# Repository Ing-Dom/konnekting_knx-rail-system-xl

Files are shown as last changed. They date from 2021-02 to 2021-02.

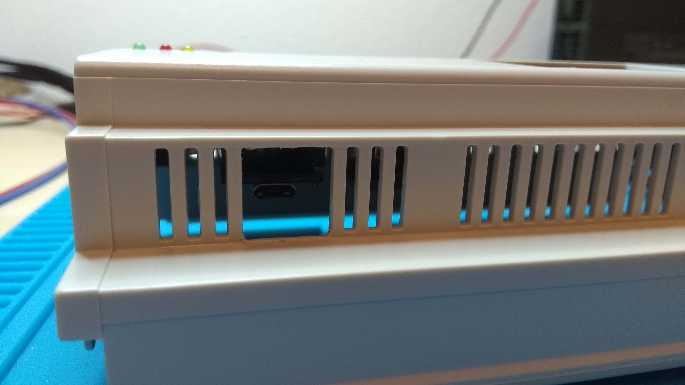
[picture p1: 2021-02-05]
hardware/KRS-XL_CB6-9-12/Pictures/IMG_20200106_220313494.jpg

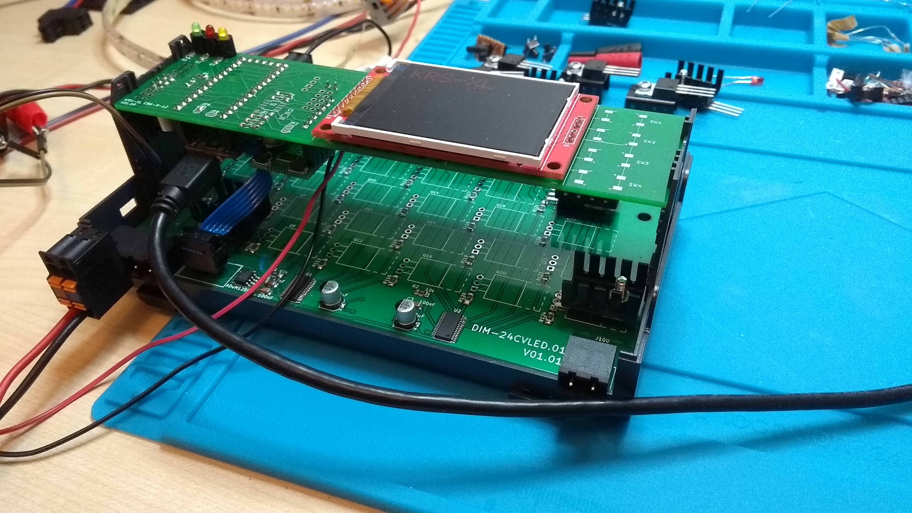
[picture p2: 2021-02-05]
hardware/KRS-XL_CB6-9-12/Pictures/IMG_20200125_214552915.jpg

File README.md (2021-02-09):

# KNX Rail System XL

The KNX Rail System XL (KRS-XL) is a bunch of modular hard- and software for building DIY KNX devices in big DIN Rail Casings (6, 9 and 12 TE). It is designed for applications with a high number of channels. 

For more information please visit the [wiki](https://gitlab.com/knx-makerstuff/knx-rail-system-xl/-/wikis/home)

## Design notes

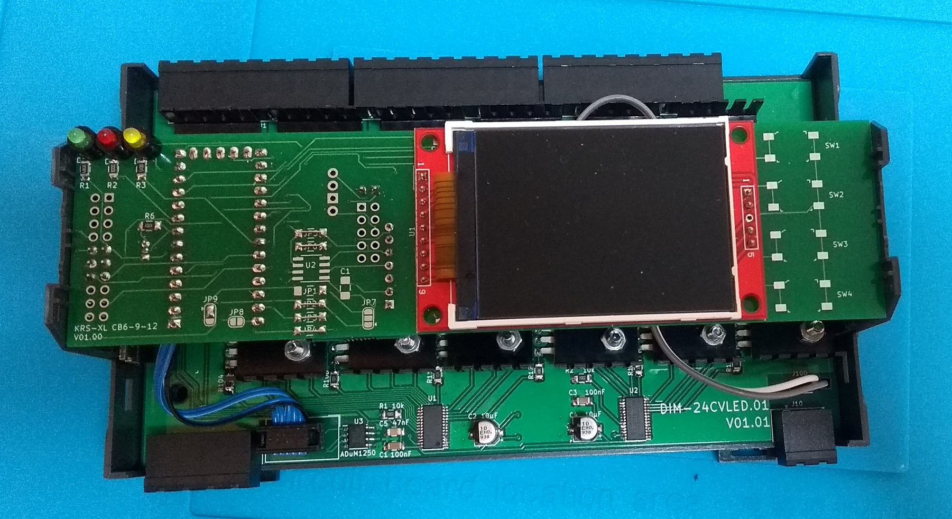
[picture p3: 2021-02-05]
hardware/KRS-XL_CB6-9-12/Pictures/IMG_20200126_205323381 - Kopie.jpg

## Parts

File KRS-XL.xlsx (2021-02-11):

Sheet: BOM
 |  |  |  | Supplier |  |  | Alt 1 |  |  |  | DIM-24CxLED (TFT)
Num | Ref | Desc | Element desc. | Supplier | ORDER-NR | Cost | Supplier | ORDER-NR | Cost
1 |  | PCB |  | KNX Makerstuff | 0100 | 4.00 € |  |  |  | 4.00 € | X
1 | J2 | Wannenstecker | Wannenstecker, 20-polig, gerade | Reichelt | WSL 20G | 0.15 € |  |  |  | 0.15 € | WSL 6G
1 | D1 | Power LED | LED, 3 mm, bedrahtet, grün, 3,2 mcd, 60° | Reichelt | LED 3MM 2MA GN | 0.12 € |  |  |  | 0.12 € | X
1 | D2 | Prog LED | LED, 3 mm, bedrahtet, rot, 3,2 mcd, 60° | Reichelt | LED 3MM 2MA RT | 0.12 € |  |  |  | 0.12 € | X
1 | D3 | Error LED | LED, 3 mm, bedrahtet, gelb, 3,2 mcd, 60° | Reichelt | LED 3MM 2MA GE | 0.12 € |  |  |  | 0.12 € | X
3 | D1-3 | LED Abstandshalter | Abstandhalter für 3 mm LEDs, Länge 5 mm | Reichelt | MEN 2818.3045 | 0.20 € |  |  |  | 0.60 € | X
1 | R1 | Vorwiderstand Power LED | SMD1206 680R | Reichelt | RND 1206 1 680 | 0.02 € |  |  |  | 0.02 € | X
1 | R2 | Vorwiderstand Prog LED | SMD1206 850R | Reichelt | RND 1206 1 820 | 0.02 € |  |  |  | 0.02 € | X
1 | R3 | Vorwiderstand Error LED | Element desc. | Reichelt | RND 1206 1 510 | 0.02 € |  |  |  | 0.02 € | X
1 | U3 | Temp Sensor | DS 18B20 | Reichelt | DS 18B20 | 1.75 € |  |  |  | 1.75 € | X
1 | R6 | DS18B20 Onewire Pullup | SMD1206 4k7 | Reichelt | RND 1206 1 4,7K | 0.02 € |  |  |  | 0.02 € | X
1 | C10 | Decoupling C µC 100N | SMD 1206 100N | Reichelt | KEM X7R1206B100N | 0.04 € |  |  |  | 0.04 € | X
1 | C11 | Decoupling C µC 10µF | 10µF | Reichelt | HD-V 10U 25 | 0.25 € |  |  |  | 0.25 € | X
2 | R4-5 | I2C Pullup | SMD1206 1k | Reichelt | RND 1206 1 1,0K | 0.02 € |  |  |  | 0.04 € | X
1 | GN1 | MicroBCU2 | MicroBCU2 | KNX Makerstuff | 0001 | 10.00 € |  |  |  | 10.00 € | X
1 | GN1 | 1x07 Buchsenleiste low profile µBCU | Buchsenleiste 1x7 | Reichelt | BL 1X10G8 2,54 | 0.21 € |  |  |  | 0.21 € | MPE 094-1-007
1 | GN1 | 1x07 Stiftleiste | Stiftleiste 1x7 | Reichelt | MPE 087-1-007 | 0.16 € |  |  |  | 0.16 € | X
1 | J1 | Header for KNX+/GND | Stiftleiste 1x2 | Reichelt | RND 205-00623 | 0.03 € |  |  |  | 0.03 € | X
1 | GN2 | Controllerboard | Adafruit ItsyBitsyM0 Express SAMD21 µC Board | DigiKey | ItsyBitsy M0 | 12.70 € | Antratek |  | 11.84 € | 12.70 € | X
2 | GN2 | 1x14 female header low profile für Controllerboard | 20pol. Buchsenleiste, gerade, RM 2,54 5mm | Reichelt | BL 1X20G 2,54 | 0.72 € |  |  |  | 1.44 € | MPE 094-1-016
1 | GN2 | 1x05 female header low profile für Controllerboard | use rest | use rest | use rest | 0.00 € |  |  |  | 0.00 € | MPE 094-1-005
1 | U1 | Display | TFT 240x320 ILI9341 2.2" | ebay | ILI9341 2.2 SPI TFT | 5.50 € |  |  |  | 5.50 € | X
4 | SW1-4 | Taster Display | SMD-Kurzhubtaster, vert. Montage, Höhe 9,5mm | Reichelt | TASTER 9319 | 0.27 € |  |  |  | 1.08 € | X
2 | C1-2 | C for magnetic coupler | SMD1206 10-100N | Reichelt | RND 1501206B4733 | 0.02 € |  |  |  | 0.04 €
1 | GN3 | Siemens BCU | Siemens Busankoppler KNX 5WG1 117-2AB12 | Voltus | UP117/12 | 25.00 € |  |  |  | 25.00 €
8 | D10-D17 | 3mm LED for LED Matrix | LED, 3 mm, bedrahtet, grün, 18 mcd, 60° | Reichelt | LED 3MM GN | 0.07 € |  |  |  | 0.56 €
8 | D10-D17 | LED Abstandshalter | Abstandhalter für 3 mm LEDs, Länge 5 mm | Reichelt | MEN 2818.3045 | 0.20 € |  |  |  | 1.60 €
3 | R10-12 | Vorwiderstand LED Matrix | SMD1206 ??? R | Reichelt | RND 1206 1 ??? | 0.02 € |  |  |  | 0.06 €
8 | SW10-17 | Taster für Tastermatrix | SMD-Kurzhubtaster, vert. Montage, Höhe 9,5mm | Reichelt | TASTER 9319 | 0.27 € |  |  |  | 2.16 €
1 | U2 | magnetic coupler KNX BCU | ADuM1201AR | Reichelt | ADUM 1201 AR | 1.70 € |  |  |  | 1.70 €
1 | U4 | 20V->3V3 DC DC StepDown | Recom R-783.3-0.5 | Conrad | 154481 - U0 | 7.03 € |  |  |  | 7.03 €
2 | GN3 | Lötstifte KNX Klemme Siemens BCU | WAGO Lötstifte für Buchsenklemmen 243-131 | Reichelt | WAGO 243-131 | 0.06 € |  |  |  | 0.12 €
1 | GN3 | 2x05 Stiftleiste Siemens BCU
 |  |  |  |  |  |  |  |  |  | 76.66 €
 | R6 | 4k7
 | SW2 | SW_Push_Dual
 | SW3 | SW_Push_Dual
 | SW4 | SW_Push_Dual
 | U1 | CR2013-MI2120
 | U2 | ADuM1201AR
 | U3 | DS18B20
 | U4 | R-783.3-0.5

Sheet: KRS-XL CB6-9-12 Bestückvariante
Variante | µBCU | Siemens BCU | Adum1201 | DC/DC | JP1 | JP2 | JP3 | JP5 | JP6 | JP7 | JP8 | JP9
µBCU mit VCC2 | 3V3+VCC2 | - | - | - | closed | closed | closed | closed | closed | open | open | je nach App
µBCU | 3V3 | - | - | - | open | closed | closed | closed | closed | open | open | 1+2
µBCU isoliert | 3V3 | - | bestückt | - | open | open | open | open | open | 1+2 | open
Siemens BCU | - | bestückt | bestückt | - | closed | open | closed | open | open | 2+3 | closed | je nach App
Siemens BCU isoliert | - | bestückt | bestückt | - | open | open | open | open | open | 2+3 | open
Siemens BCU mit DC/DC | - | bestückt | bestückt | bestückt | closed | open | closed | open | open | 2+3 | open | je nach App
isolated BCU and 5V power from app |  |  |  |  |  |  |  |  |  |  | closed | 2+3
isolated bcu and 3v3 power from app |  |  |  |  |  |  |  |  |  |  | open | 1+2

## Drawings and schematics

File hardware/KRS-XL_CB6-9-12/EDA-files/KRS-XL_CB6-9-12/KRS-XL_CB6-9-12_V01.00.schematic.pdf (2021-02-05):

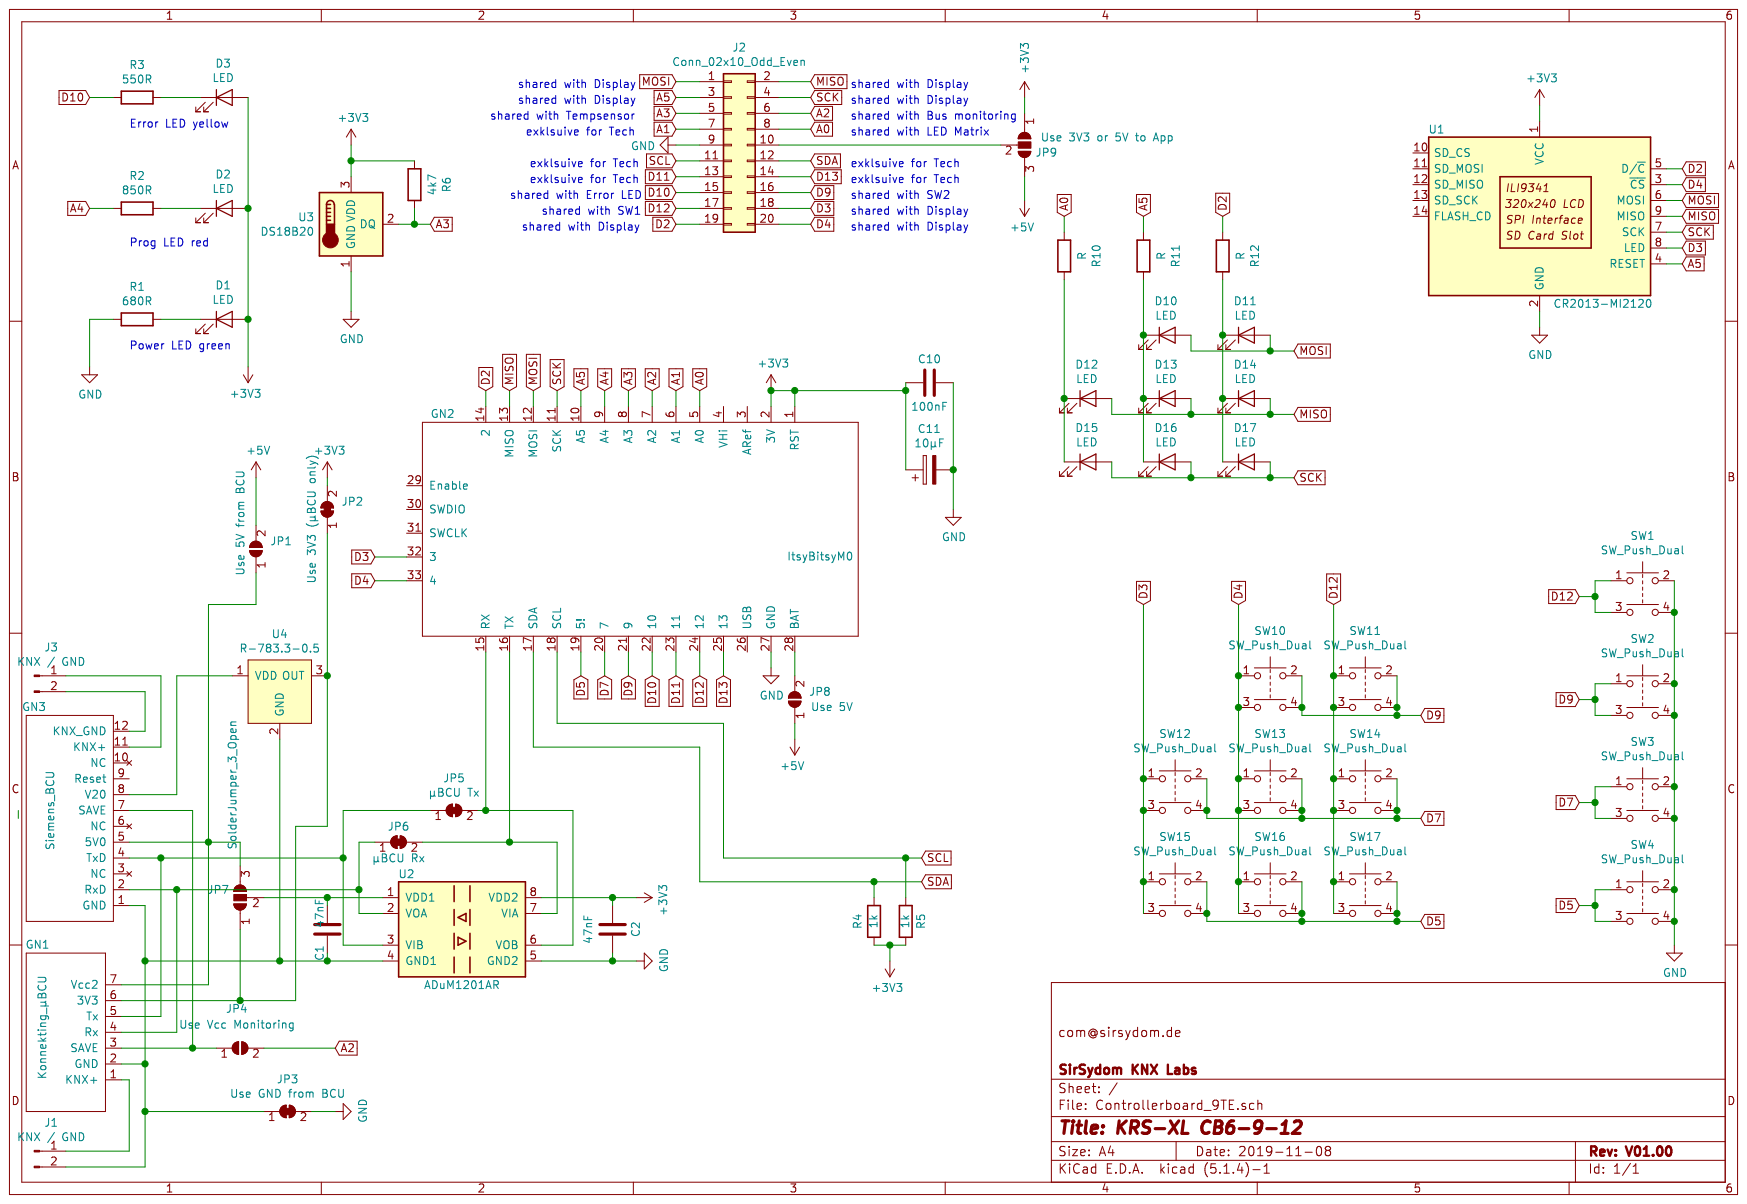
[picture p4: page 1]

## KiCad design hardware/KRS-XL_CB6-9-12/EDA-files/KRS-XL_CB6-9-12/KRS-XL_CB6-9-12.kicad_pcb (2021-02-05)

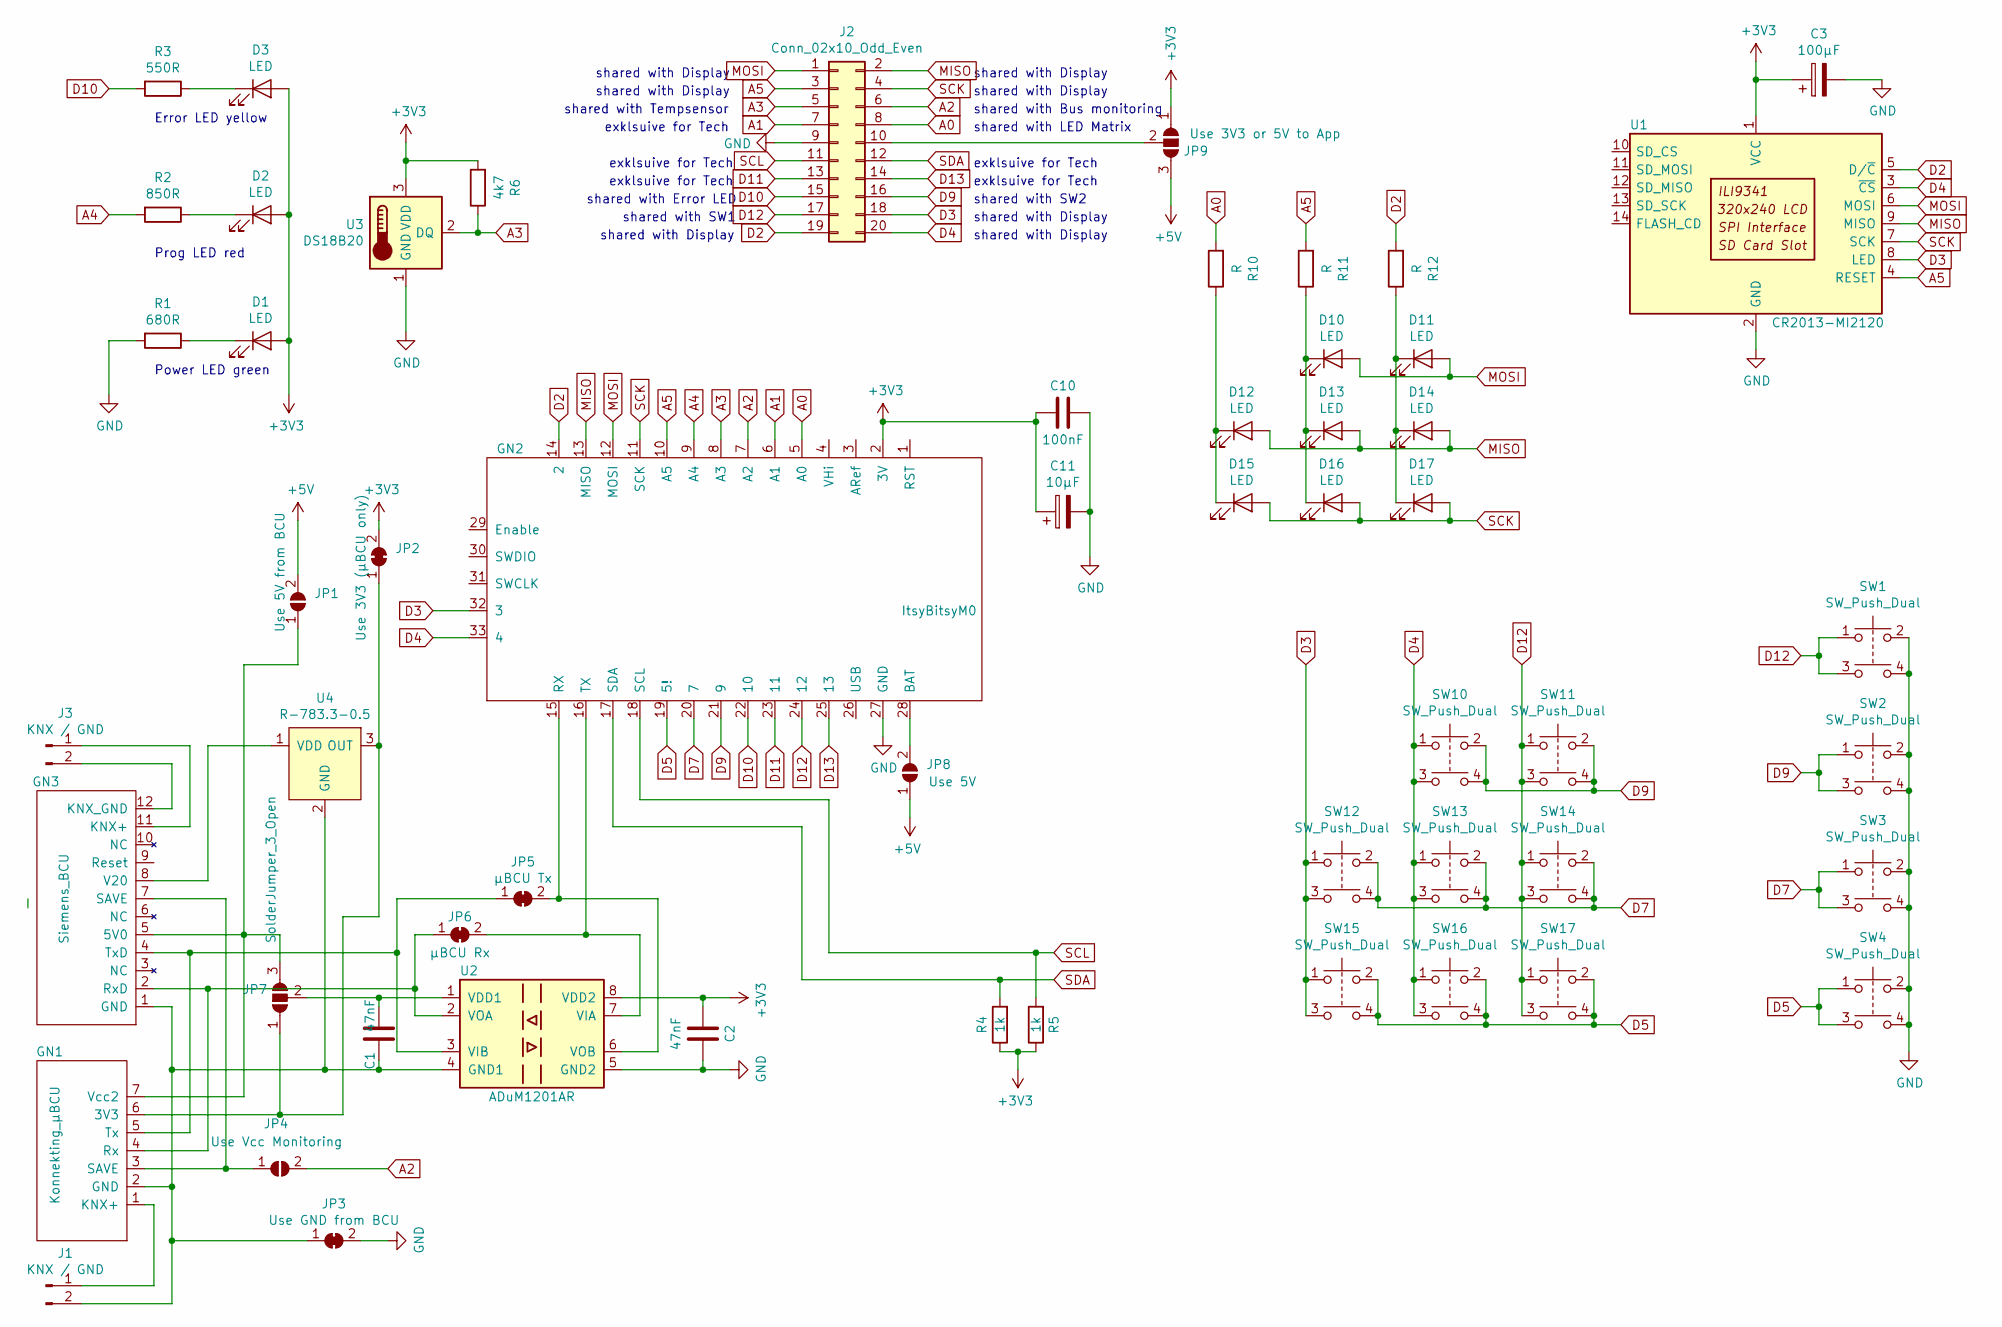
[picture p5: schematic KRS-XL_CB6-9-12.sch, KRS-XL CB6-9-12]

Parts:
C1, C2: 47nF; C_1206_3216Metric_Pad1.42x1.75mm_HandSolder
C3: 100µF; CP_Elec_5x5.3
C10: 100nF; C_1206_3216Metric_Pad1.42x1.75mm_HandSolder
C11: 10µF; CP_Elec_5x5.3
D1, D2, D3, D10, D11, D12, D13, D14, D15, D16, D17: LED; LED_D3.0mm_Clear
GN1: Konnekting_µBCU; Konnekting_BCU
GN2: ItsyBitsyM0
GN3: Siemens_BCU; Siemens_UP117_12_flat
J1, J3: KNX / GND; PinHeader_1x02_P2.54mm_Vertical
J2: Conn_02x10_Odd_Even; IDC-Header_2x10_P2.54mm_Vertical
JP1: Use 5V from BCU; 3mm_solderjumper
JP2: Use 3V3 (µBCU only); 3mm_solderjumper
JP3: Use GND from BCU; 3mm_solderjumper
JP4: Use Vcc Monitoring; 3mm_solderjumper
JP5: µBCU Tx; 3mm_solderjumper
JP6: µBCU Rx; 3mm_solderjumper
JP7: SolderJumper_3_Open; SolderJumper-3_P1.3mm_Open_RoundedPad1.0x1.5mm
JP8: Use 5V; SolderJumper-2_P1.3mm_Open_RoundedPad1.0x1.5mm
JP9: Use 3V3 or 5V to App; SolderJumper-3_P1.3mm_Open_RoundedPad1.0x1.5mm
R1: 680R; R_1206_3216Metric_Pad1.42x1.75mm_HandSolder
R2: 850R; R_1206_3216Metric_Pad1.42x1.75mm_HandSolder
R3: 550R; R_1206_3216Metric_Pad1.42x1.75mm_HandSolder
R4, R5: 1k; R_1206_3216Metric_Pad1.42x1.75mm_HandSolder
R6: 4k7; R_1206_3216Metric_Pad1.42x1.75mm_HandSolder
R10, R11, R12: R; R_1206_3216Metric_Pad1.42x1.75mm_HandSolder
SW1, SW2, SW3, SW4, SW10, SW11, SW12, SW13, SW14, SW15, SW16, SW17: SW_Push_Dual; Switch_Tactile_SMD_6x6mm
U1: CR2013-MI2120; CR2013-MI2120_wo_holes
U2: ADuM1201AR; SOIC-8_3.9x4.9mm_P1.27mm
U3: DS18B20; TO-92_Inline
U4: R-783.3-0.5; SIP-3_P2.54mm_OR_4; MPN R-78E5.0-0.5; Digi-Key_PN 945-1648-5-ND

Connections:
+3V3: C2.2, C3.1, C10.2, C11.1, D1.2 (A), D2.2 (A), D3.2 (A), GN2.2 (3V), JP2.2 (B), JP9.1 (A), R4.1, R5.1, R6.2, U1.1 (VCC), U2.8 (VDD2), U3.3 (VDD)
+5V: JP1.2 (B), JP8.1 (A), JP9.3 (B)
A0: GN2.5 (A0), J2.8, R10.2
A1: GN2.6 (A1), J2.7
A2: GN2.7 (A2), J2.6, JP4.2 (B)
A3: GN2.8 (A3), J2.5, R6.1, U3.2 (DQ)
A4: GN2.9 (A4), R2.2
A5: GN2.10 (A5), J2.3, R11.2, U1.4 (RESET)
D2: GN2.14 (2), J2.19, R12.2, U1.5 (D/~C)
D3: GN2.32 (3), J2.18, SW12.1, SW12.3, SW15.1, SW15.3, U1.8 (LED)
D4: GN2.33 (4), J2.20, SW10.1, SW10.3, SW13.1, SW13.3, SW16.1, SW16.3, U1.3 (~CS)
D5: GN2.19 (5!), SW4.1, SW4.3, SW15.2, SW15.4, SW16.2, SW16.4, SW17.2, SW17.4
D7: GN2.20 (7), SW3.1, SW3.3, SW12.2, SW12.4, SW13.2, SW13.4, SW14.2, SW14.4
D9: GN2.21 (9), J2.16, SW2.1, SW2.3, SW10.2, SW10.4, SW11.2, SW11.4
D10: GN2.22 (10), J2.15, R3.2
D11: GN2.23 (11), J2.13
D12: GN2.24 (12), J2.17, SW1.1, SW1.3, SW11.1, SW11.3, SW14.1, SW14.3, SW17.1, SW17.3
D13: GN2.25 (13), J2.14
GND: C2.1, C3.2, C10.1, C11.2, GN2.27 (GND), J2.9, JP3.2 (B), R1.2, SW1.2, SW1.4, SW2.2, SW2.4, SW3.2, SW3.4, SW4.2, SW4.4, U1.2 (GND), U2.5 (GND2), U3.1 (GND)
MISO: D12.2 (A), D13.2 (A), D14.2 (A), GN2.13 (MISO), J2.2, U1.9 (MISO)
MOSI: D10.2 (A), D11.2 (A), GN2.12 (MOSI), J2.1, U1.6 (MOSI)
unnamed: C1.1, JP7.2 (C), U2.1 (VDD1)
unnamed: C1.2, GN1.2 (GND), GN3.1 (GND), J1.2, JP3.1 (A), U2.4 (GND1), U4.2 (GND)
unnamed: D1.1 (K), R1.1
unnamed: D2.1 (K), R2.1
unnamed: D3.1 (K), R3.1
unnamed: D10.1 (K), D13.1 (K), D16.1 (K), R11.1
unnamed: D11.1 (K), D14.1 (K), D17.1 (K), R12.1
unnamed: D12.1 (K), D15.1 (K), R10.1
unnamed: GN1.1 (KNX+), J1.1
unnamed: GN1.3 (SAVE), GN3.7 (SAVE), JP4.1 (A)
unnamed: GN1.4 (Rx), GN3.2 (RxD), JP6.1 (A), U2.2 (VOA)
unnamed: GN1.5 (Tx), GN3.4 (TxD), JP5.1 (A), U2.3 (VIB)
unnamed: GN1.6 (3V3), JP2.1 (A), JP7.1 (A), U4.3 (OUT)
unnamed: GN1.7 (Vcc2), GN3.5 (5V0), JP1.1 (A), JP7.3 (B)
unnamed: GN2.15 (RX), JP5.2 (B), U2.6 (VOB)
unnamed: GN2.16 (TX), JP6.2 (B), U2.7 (VIA)
unnamed: GN2.28 (BAT), JP8.2 (B)
unnamed: GN3.8 (V20), U4.1 (VDD)
unnamed: GN3.11 (KNX+), J3.1
unnamed: GN3.12 (KNX_GND), J3.2
unnamed: J2.10, JP9.2 (C)
SCK: D15.2 (A), D16.2 (A), D17.2 (A), GN2.11 (SCK), J2.4, U1.7 (SCK)
SCL: GN2.18 (SCL), J2.11, R5.2
SDA: GN2.17 (SDA), J2.12, R4.2

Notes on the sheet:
Power LED green
Prog LED red
Error LED yellow
shared with Display
shared with SW1
shared with SW2
exklsuive for Tech
shared with Error LED
shared with Tempsensor
shared with Bus monitoring
shared with LED Matrix

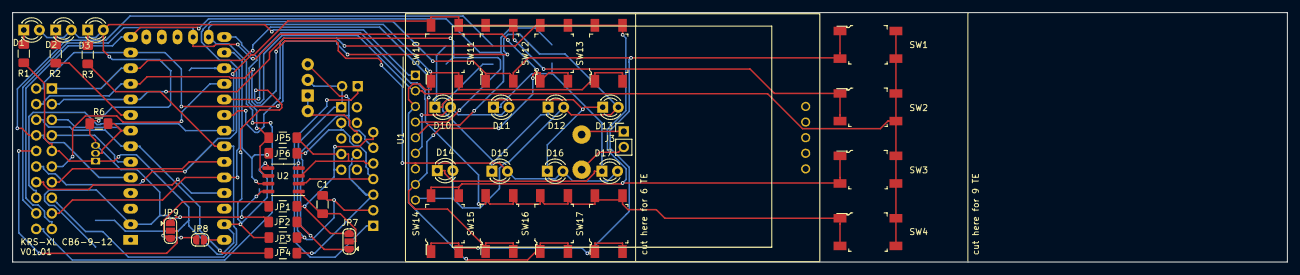
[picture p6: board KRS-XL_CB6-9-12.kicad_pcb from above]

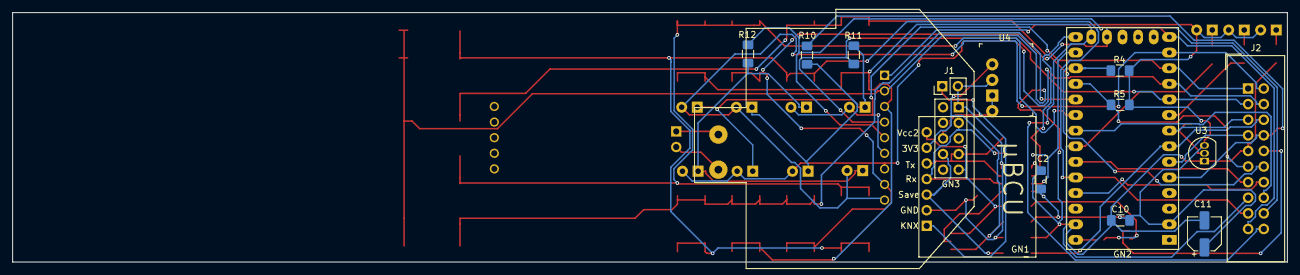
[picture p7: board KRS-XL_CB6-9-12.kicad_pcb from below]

Board: 2 copper layers, 207.5 x 40.6 mm, 55 parts (15 on the bottom side), 45 nets.

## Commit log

2021-02-05 KRS-XL_CB6-9-12_V01.00 from sirsydom/konnekting_common
    [Controllerboard_9TE.dsn, Controllerboard_9TE.kicad_pcb, Controllerboard_9TE_auto.dsn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]
2021-02-05 worked on V01.01 - RST of ItsyBitsy disconnected from 3v3
    [KRS-XL_CB6-9-12-B_Cu.gbr, KRS-XL_CB6-9-12-B_Mask.gbr, KRS-XL_CB6-9-12-B_SilkS.gbr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]
2021-02-11 added PCB render, improved BOM
    [KRS-XL.xlsx]
